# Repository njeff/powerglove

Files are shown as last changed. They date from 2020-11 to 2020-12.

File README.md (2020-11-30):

# powerglove

Jeffrey Ni and Leon Wu

WIP haptic feedback distance sensing glove.

### PCB

<p align="center">
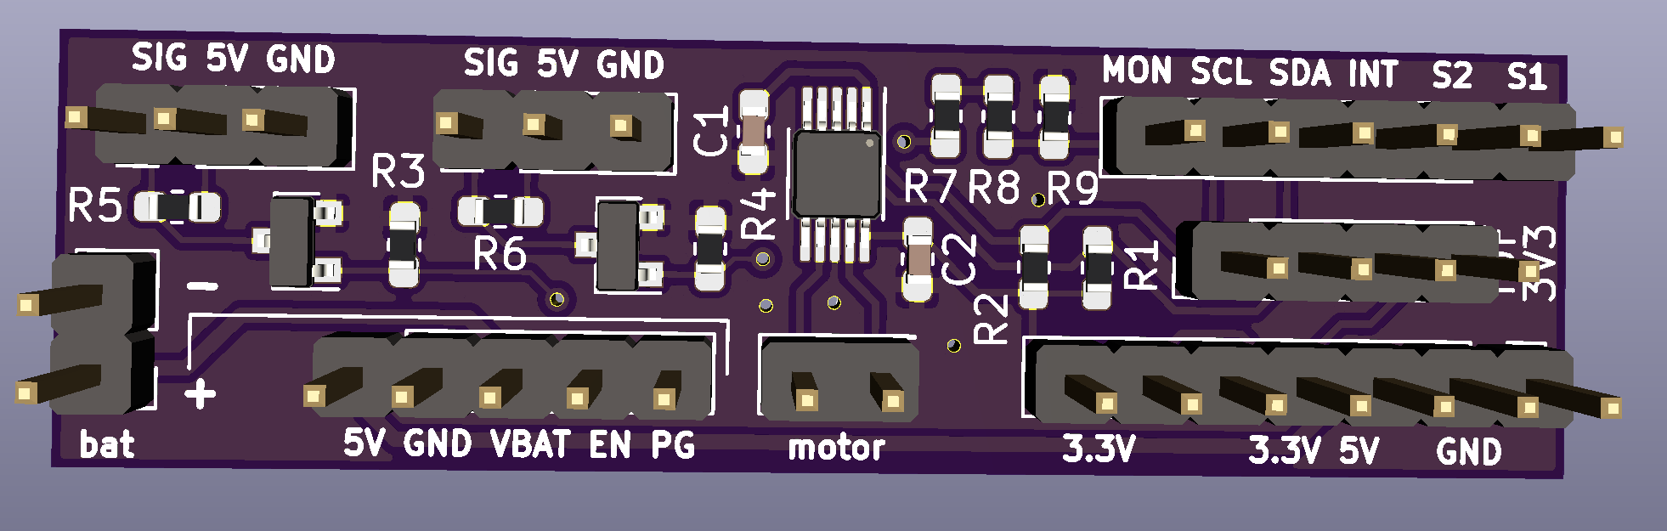
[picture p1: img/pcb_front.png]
    
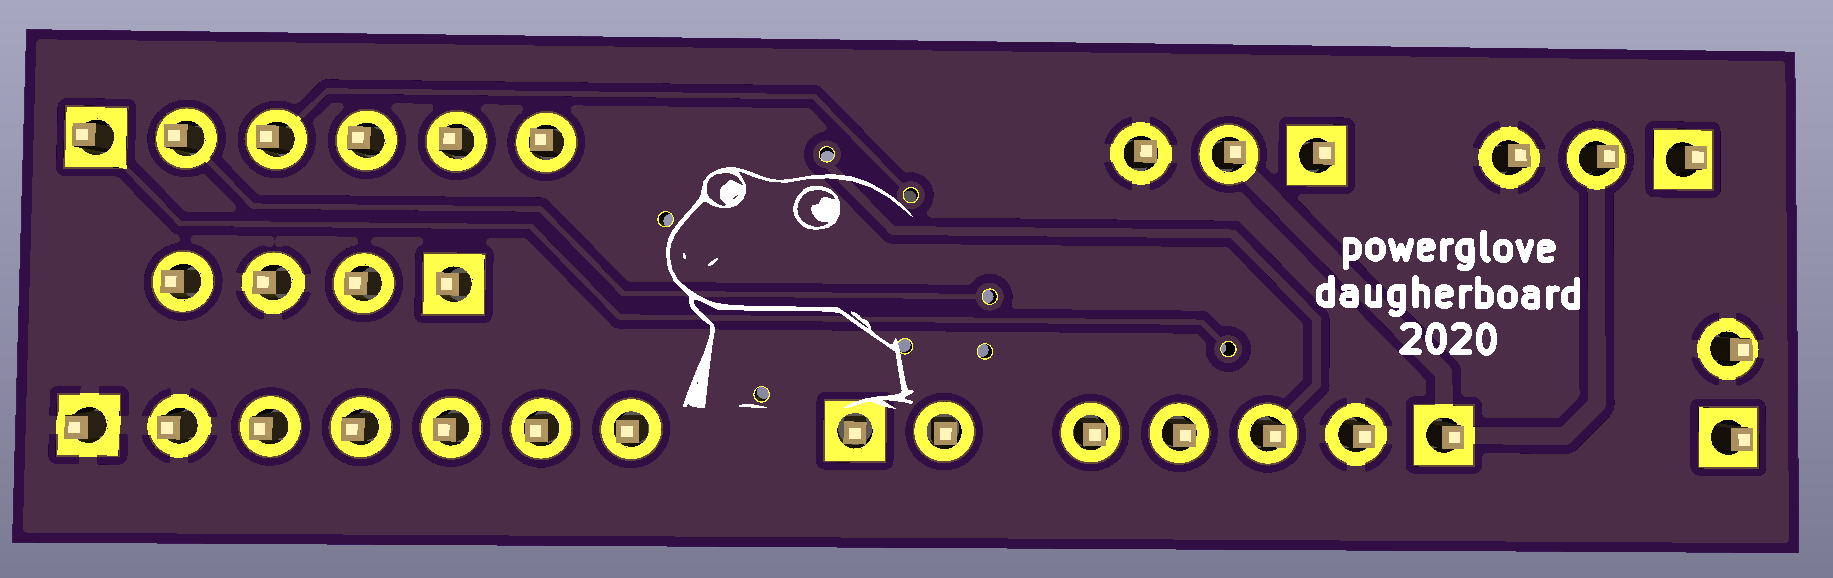
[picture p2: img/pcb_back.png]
    
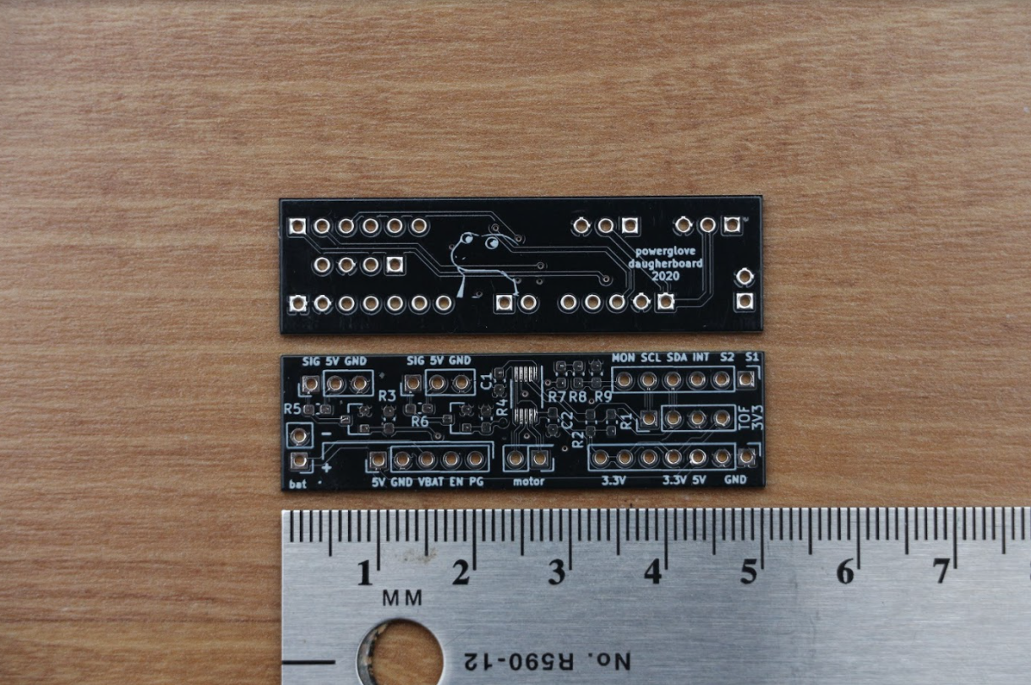
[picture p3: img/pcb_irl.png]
     
</p>

### Hardware Design

<p align="center">
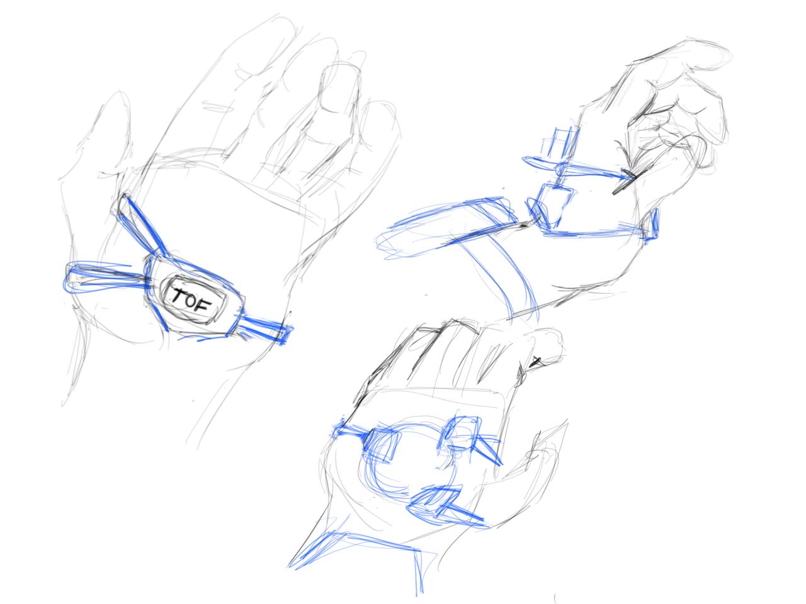
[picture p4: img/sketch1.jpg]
    
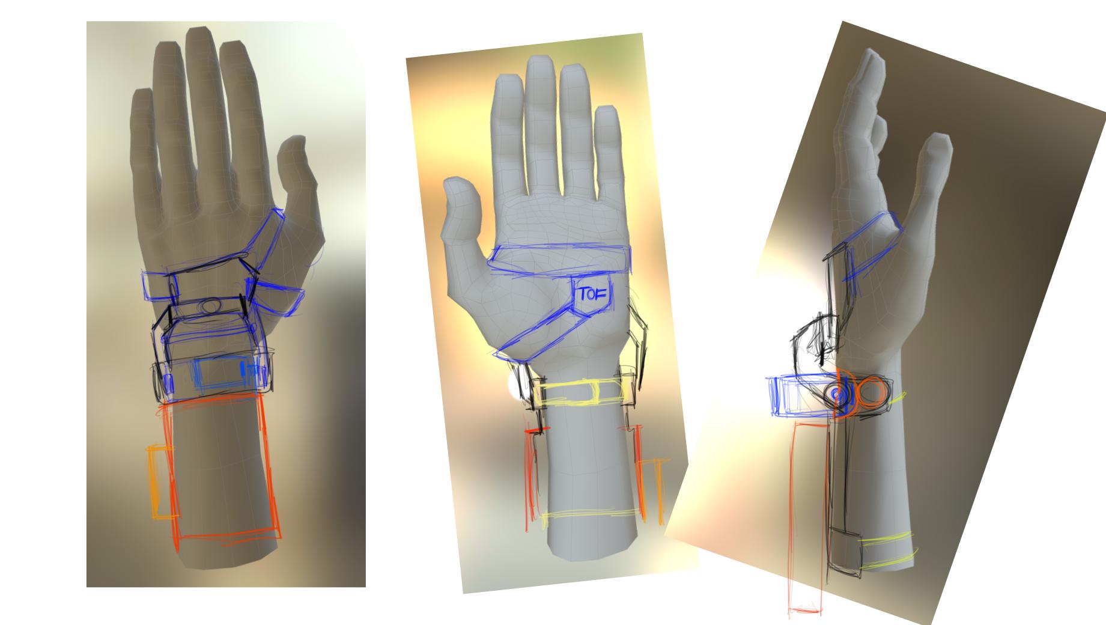
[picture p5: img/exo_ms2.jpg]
    
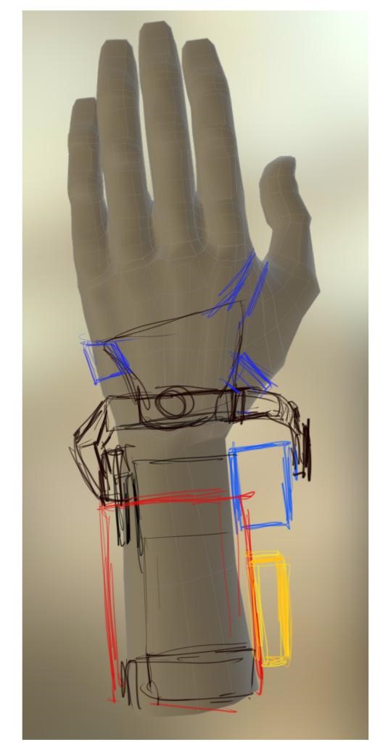
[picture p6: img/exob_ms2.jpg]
     
</p>

### Integration

<p align="center">
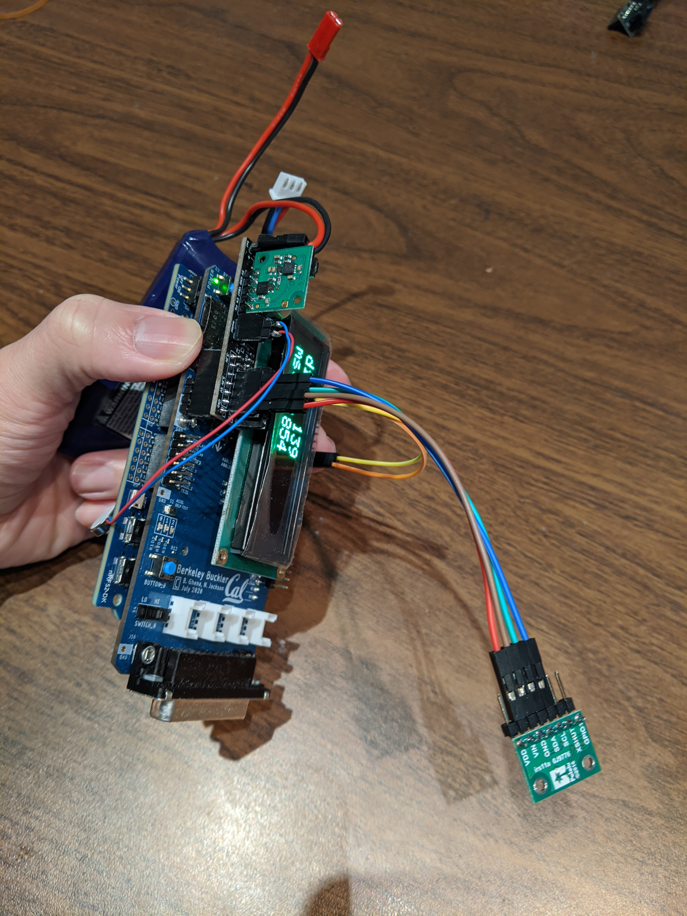
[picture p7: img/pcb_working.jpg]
    
</p>

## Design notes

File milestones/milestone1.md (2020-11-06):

# Milestone 1

## Git Repo
https://github.com/njeff/powerglove

## Architecture Drawing

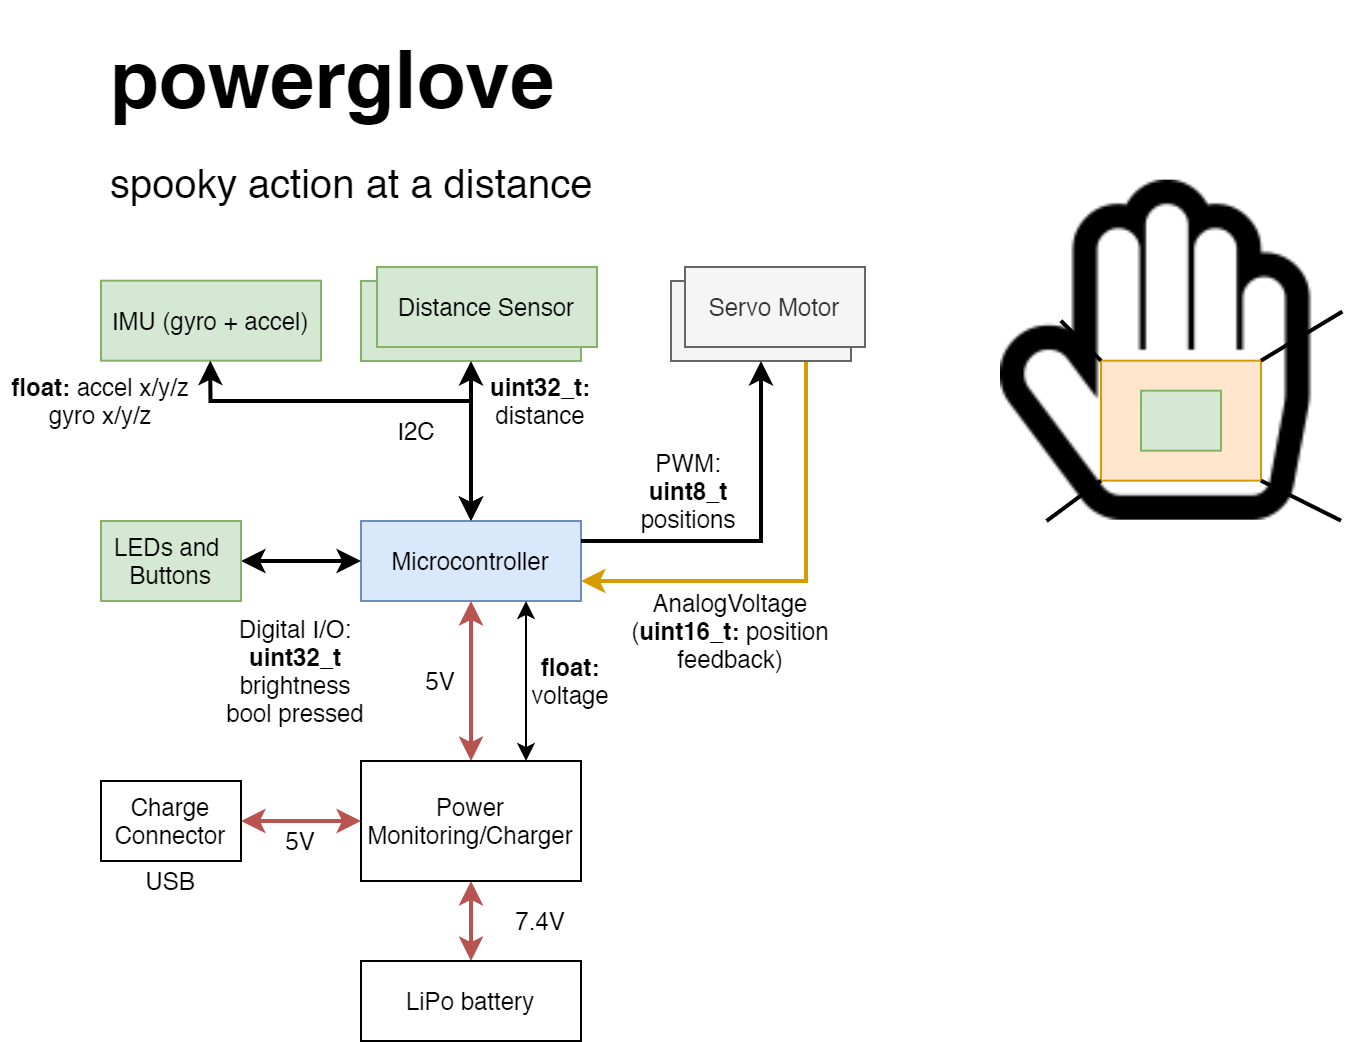
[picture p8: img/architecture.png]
Architecture Drawing


## Conceptual Sketch

Sketch

## Sensors

Ideally, the sensors are small, simple devices that can easily be integrated into the user's hand. 

* Distance/Proximity Sensor(s) - Time of Flight
    * VL53L0 - Time of Flight Distance Ranging Sensor: breakout boards are pretty flat, i2c interface with 1mm resolution, ~30mm-1m linear sensing
* Acceleration/Velocity Sensor - Simple 3/6DoF Velocity Sensing
    * NRF built in? 
    * 6DOF IMU - i.e. LSM6DS3, MPU6050
    * Provides essential secondary input signal for tracking hand motion

## Actuators

For actually generating the force, we plan to have some servos linked to a plate in the palm

* 2 or 3 micro servomotors mounted on the back of the hand that have position feedback outputs (e.g. [this](https://www.pololu.com/product/3436).)
* Some inspiration for the idea came from [this video on haptics](https://www.youtube.com/watch?v=UFgp7A1IK7o).

## Resources

We will use existing libraries for the distance sensor, found [here](https://www.st.com/en/embedded-software/stsw-img005.html). They may need slight porting for use with the NRF which we can do.

The IMU, if we use the one on the boards we have, already has libraries for it from lab.

Mechanical assembly: between the 2 of us exist:
* CNC mill
* 3D printer
* Various mechanical and electrical components

## Additional Circuits

* Portable Power: LiPo (7.4V) and charging/monitoring circuit
    * Detect low charge and enter low power mode or turn off

## Possible Risks

* The major risk is getting hardware (like the actual hand mount and actuators) up in a reasonable time. This takes CAD work, manufacturing, and multiple interations that can take time from software development and refinement of the "embedded system" as a whole.
* Haptic feedback not enough for appropriate user response, need testing of the human interaction early.

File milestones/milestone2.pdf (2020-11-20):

## powerglove: milestone 2

Jeffrey Ni and Leon Wu

## Progress

- PCB design done and sent out for fabrication:

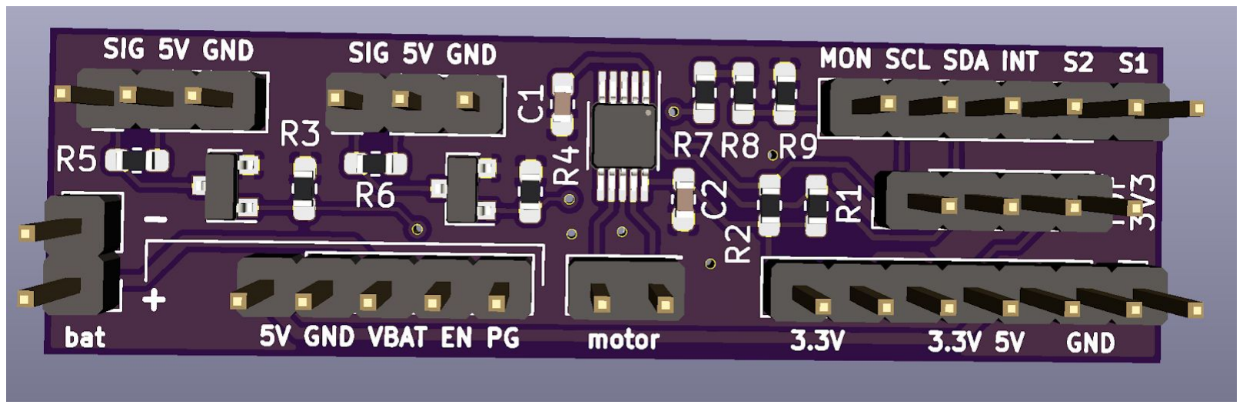
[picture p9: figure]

- Toolchain setup for the Buckler and our Custom FW
- Already have the firmware driver for the haptics ready; just need to test on actual hardware
- See at: https://github.com/njeff/powerglove
- Initial state machine plan (this may change to include a calibration phase for the hand with the servo feedback):

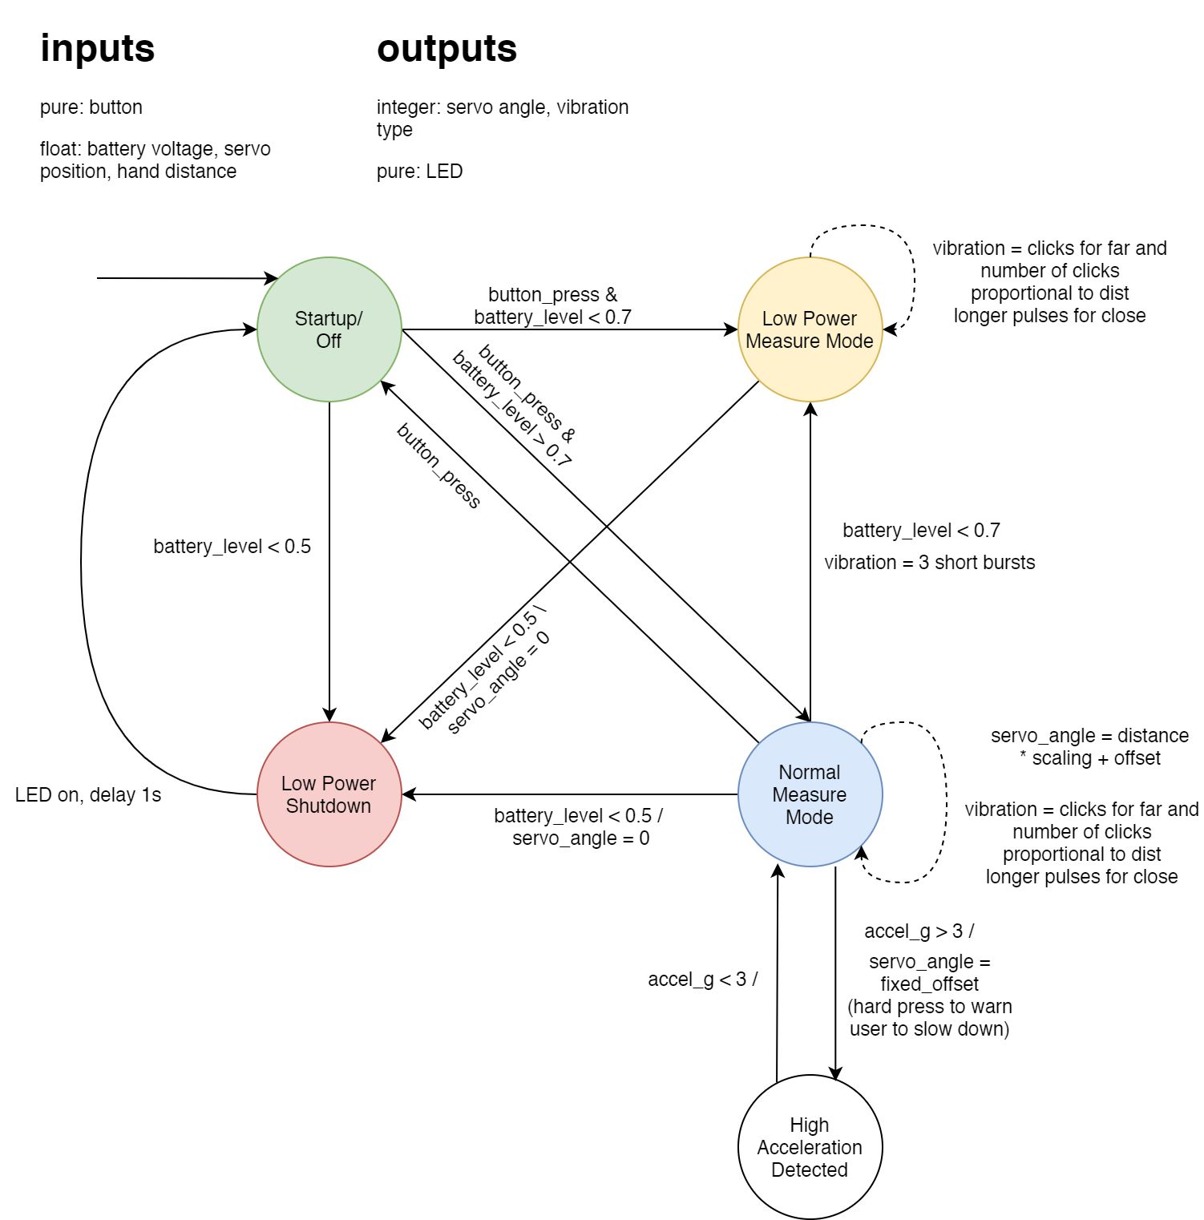
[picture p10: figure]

- Have some initial mock-ups of the mechanical design in cardboard
- We need to more carefully consider the servo mounting position as well as whether we have direct or indirect actuation.

## Changes to Scope

- Single servo palm actuator and vibration motors w/ special drivers for more than just on/off vibration
- Reduces mechanical complexity and reduces power draw

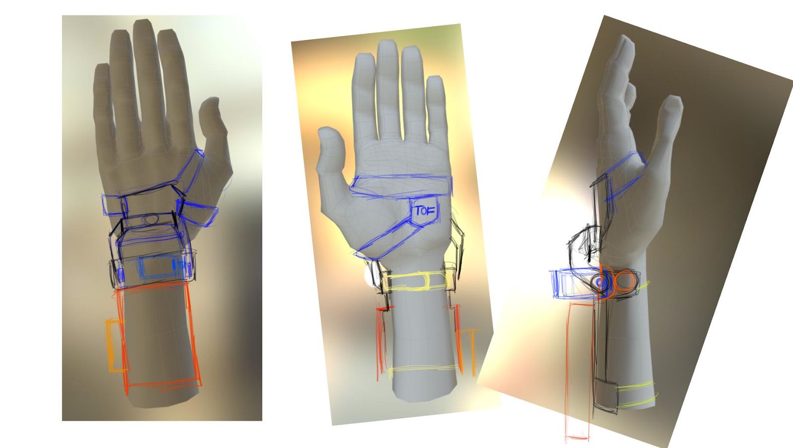
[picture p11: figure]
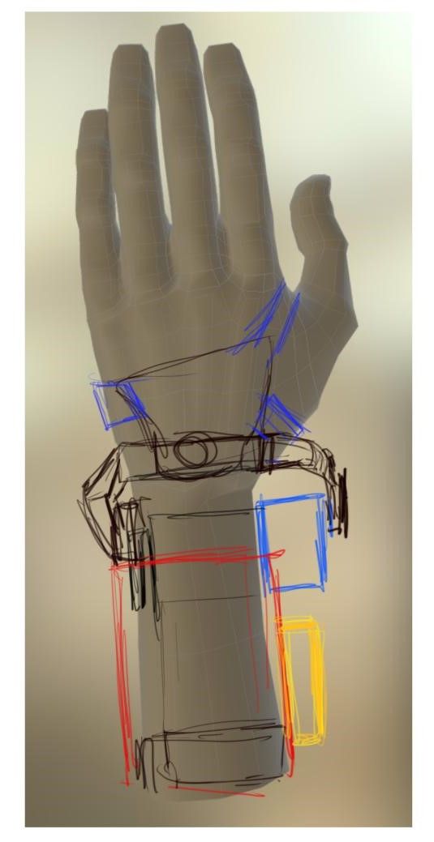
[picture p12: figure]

- How the device will actually operate is still mostly in the air, simply due do the fact that we need to experience the haptics in order to better understand how they should be used

## Resources to Still Get

- Hardware is on the way: ordered parts, PCB
- Already have the vibration motors, jumpers, and battery here
- Should not need anything extra (hopefully)
- From a code standpoint, we still need to work on porting over drivers for one of the sensors, but the main foundation is there.
- Not so much a resource, but we need to think more about how to mount the servo and the actuation arm.
- Likely need different servo horn

## Schedule of Remaining Time

- 10/28: Project proposal complete
- 11/4: Lock down the scope of what kind of haptic actuator/force we want to use
- 11/6: Milestone 1: Design state machine for this system
- 11/12: PCB sent out for manufacturing, initial prototyping of the physical layout done

- 11/16: Milestone 2: Code for initial haptic movement running; can see movement on breadboard system (parts likely come around now - update: not yet...)
- Leon: have some preliminary CAD or real-life mock-up design of the actuator
- Jeffrey: port ToF sensor driver and have servos working
- 11/18: Leon: mechanical mockups on actual arm
- 11/20: Continued refinement, Jeffrey: hopefully receive custom PCB and assemble
- 11/25: Both of us: First full integration on hand, simultaneously work on improving fit and haptic function
- 11/30: Both: Refined hardware working
- 12/2: Continued testing, begin writing report and create video
- 12/9: Both: Finalize everything
- 12/15: Project Expo, report due two days later

## Risks

The main risk is still the same one as before: getting hardware working is nontrivial and integration is not that simple, especially when designing for a portable application on the hand. We do now have a fall back though with the haptic motors in case the physical servo drive turns out to be too difficult to get working in time (but at the very least we would have it working on the bench and not on the hand).

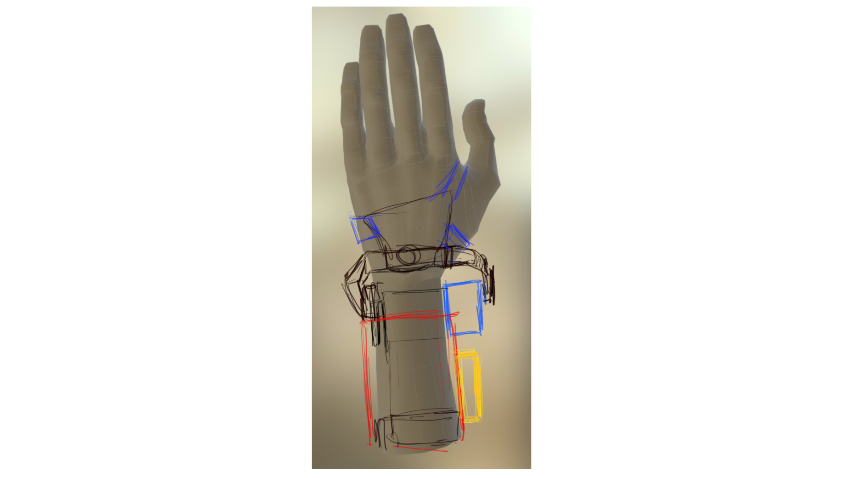
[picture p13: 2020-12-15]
img/exob_ms2.tif

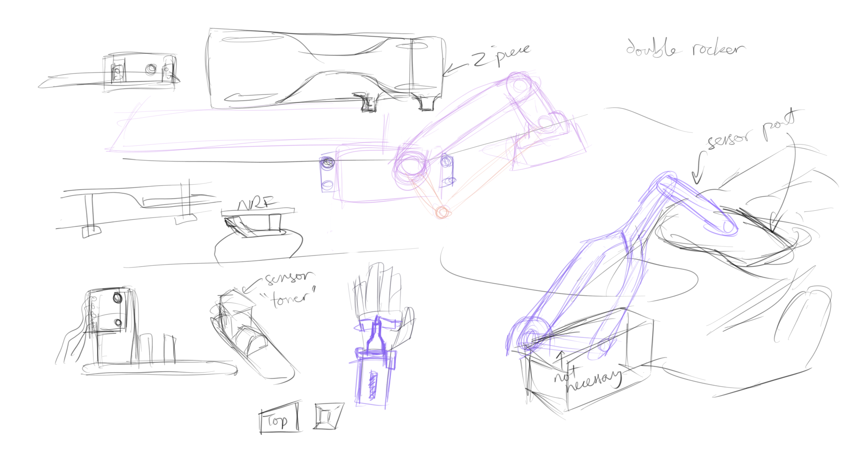
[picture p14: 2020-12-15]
img/exoc_bar1.tif

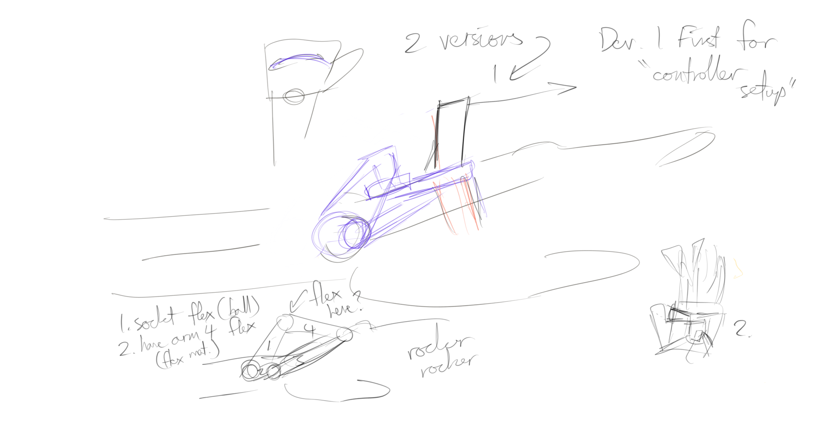
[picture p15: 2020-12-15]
img/exoc_bar.tif

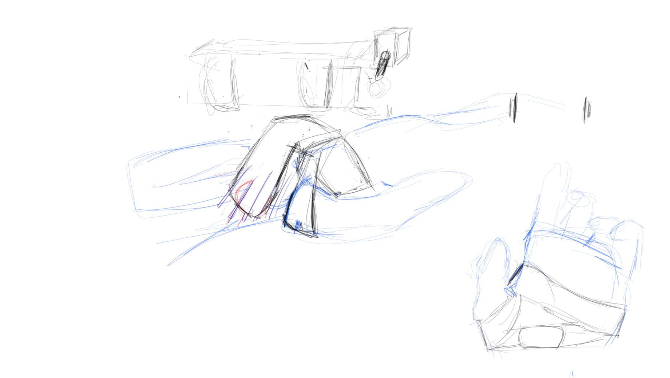
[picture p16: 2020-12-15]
img/temp.tif

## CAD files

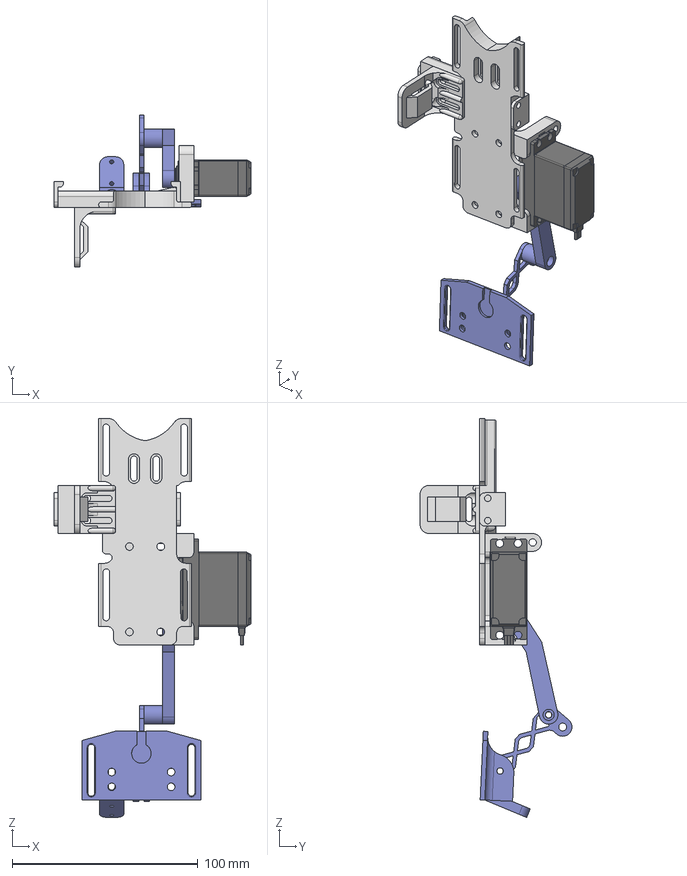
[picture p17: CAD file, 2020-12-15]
mechanical/left_assembly.step
105.9 x 81.8 x 215.0 mm
servo
fullwrist
servohorn
standoff
flex_linkage
battery_slotter
flat_side_clip x 2

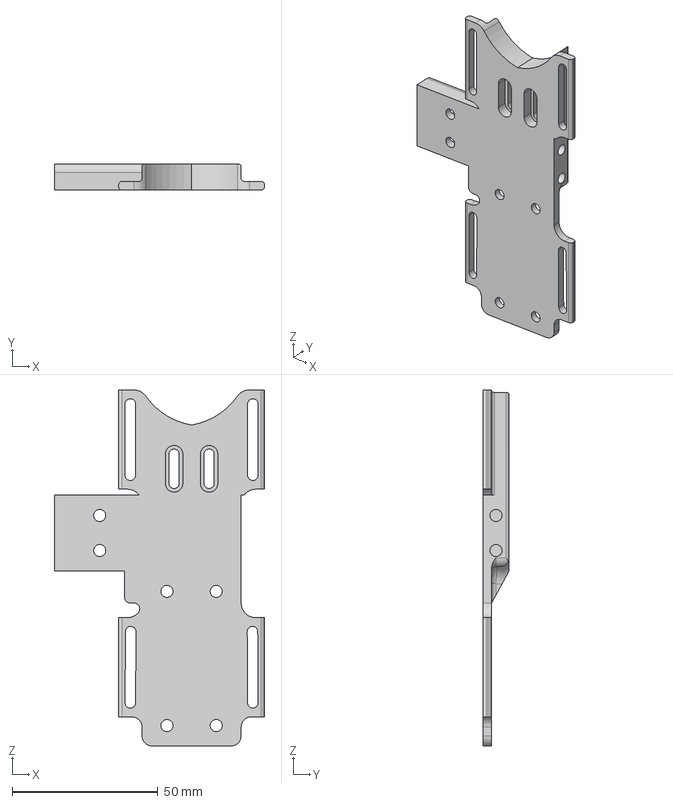
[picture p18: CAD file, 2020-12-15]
mechanical/fullwrist.step
72.0 x 9.00 x 122.0 mm

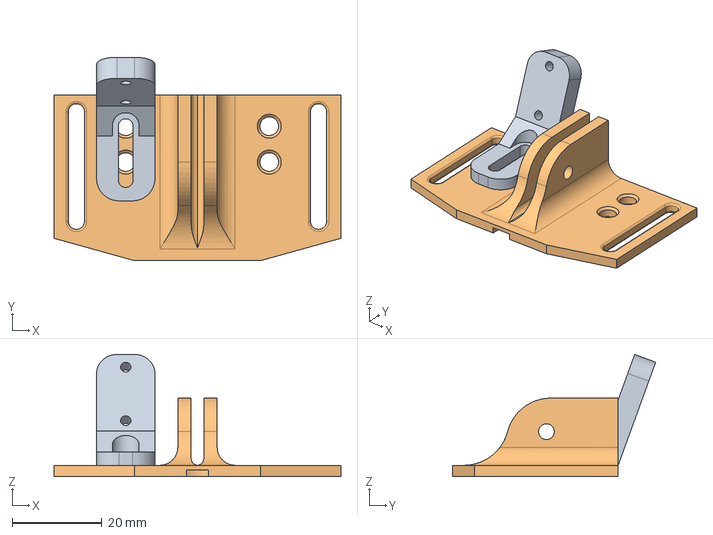
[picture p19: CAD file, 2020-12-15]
mechanical/back_hand.step
64.0 x 45.4 x 27.2 mm

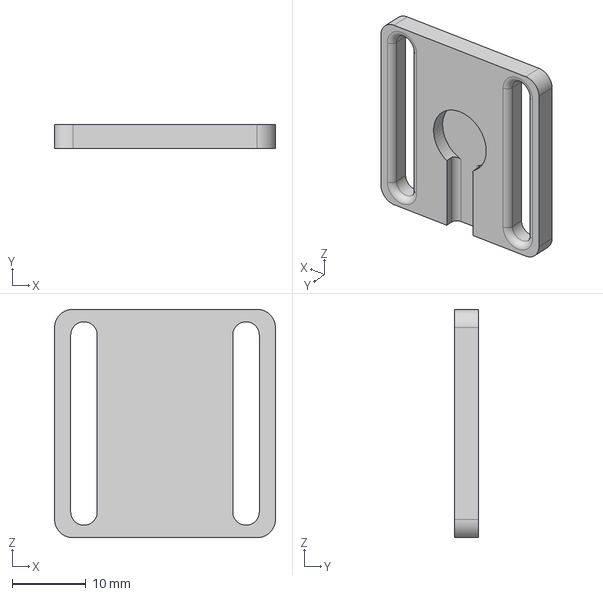
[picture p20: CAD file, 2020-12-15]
mechanical/palm_sensorless.step
30.0 x 3.20 x 31.0 mm

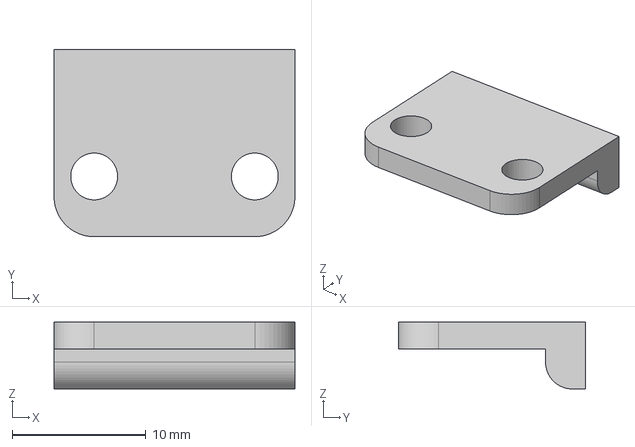
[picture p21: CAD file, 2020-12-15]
mechanical/flat_side_clip.step
18.0 x 14.0 x 5.00 mm

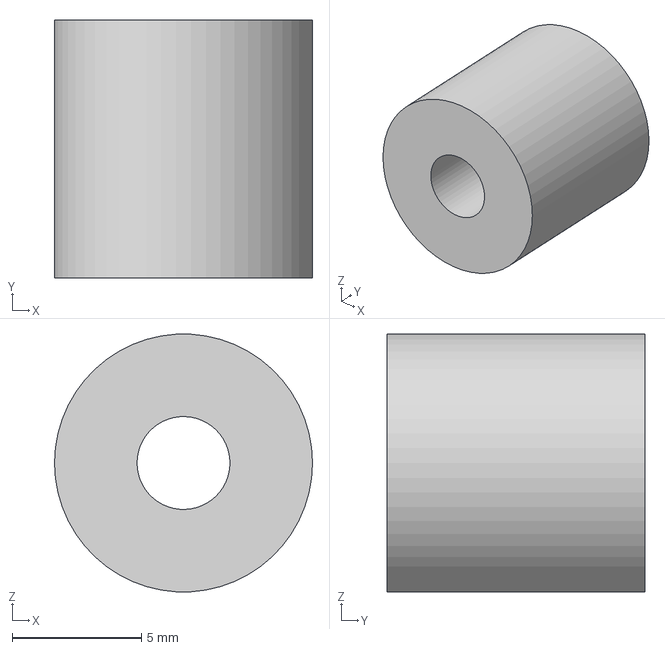
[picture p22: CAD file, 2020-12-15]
mechanical/standoff.step
10.0 x 10.0 x 9.98 mm

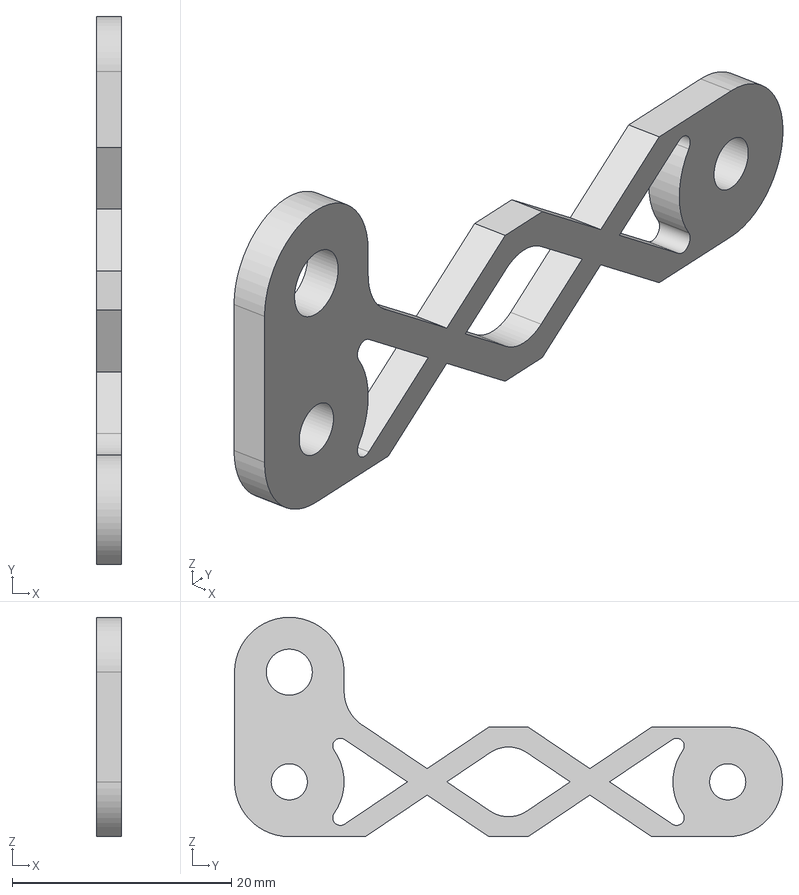
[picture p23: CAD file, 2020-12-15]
mechanical/flex_linkage.step
2.30 x 50.0 x 20.0 mm

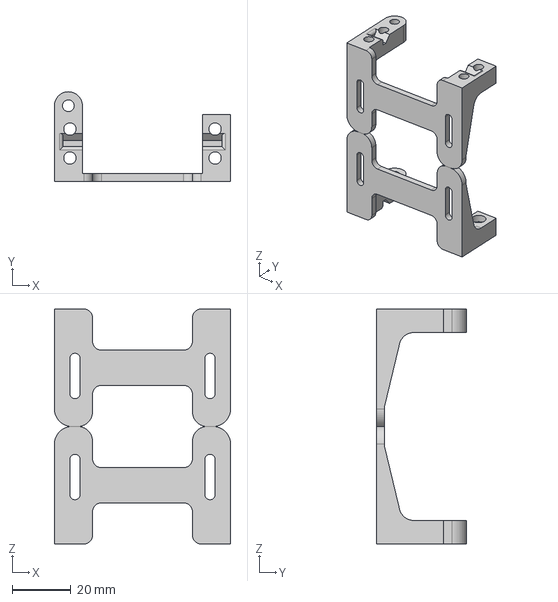
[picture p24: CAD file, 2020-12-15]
mechanical/servo_mount.step
60.0 x 30.5 x 80.0 mm

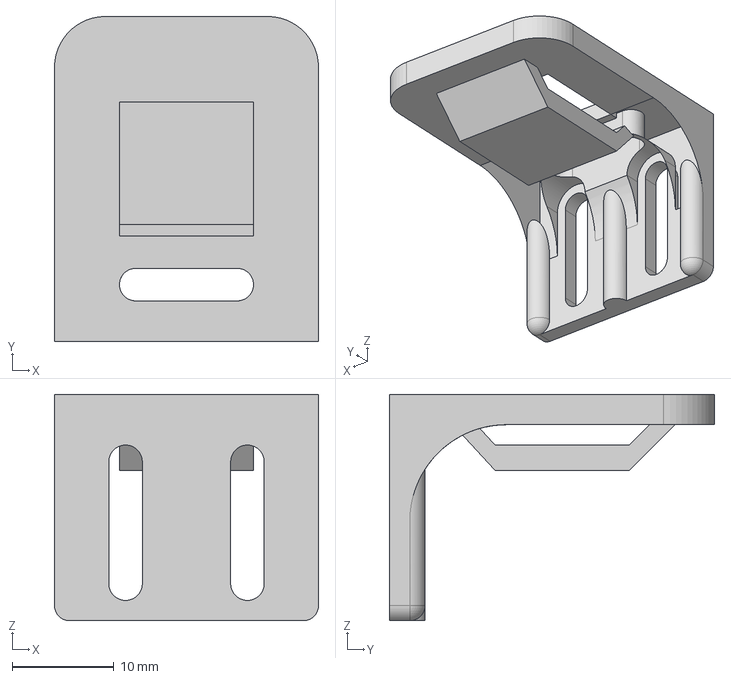
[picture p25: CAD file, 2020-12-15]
mechanical/battery_slotter.step
26.0 x 32.0 x 22.3 mm

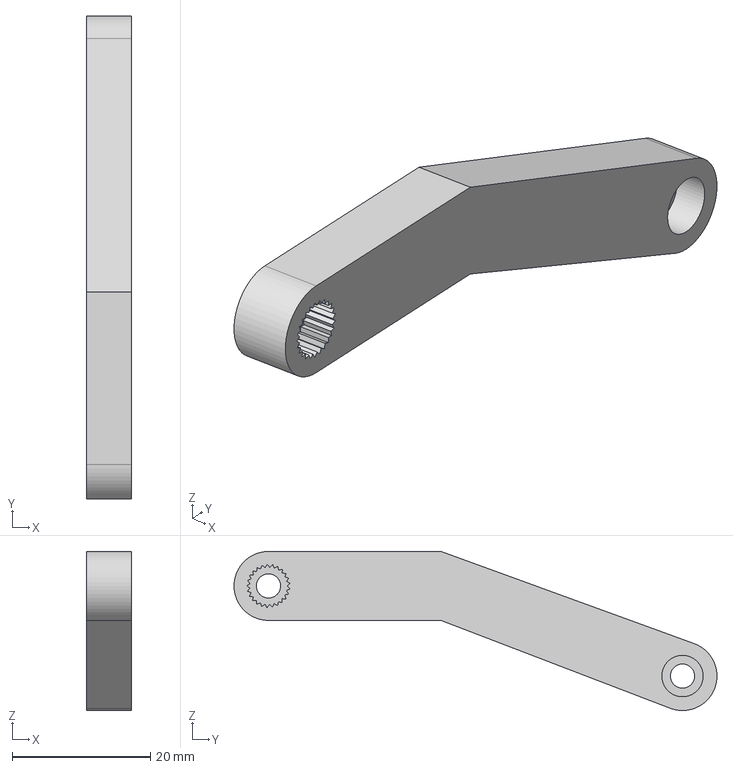
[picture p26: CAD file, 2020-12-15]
mechanical/servohorn.step
6.50 x 70.0 x 23.1 mm

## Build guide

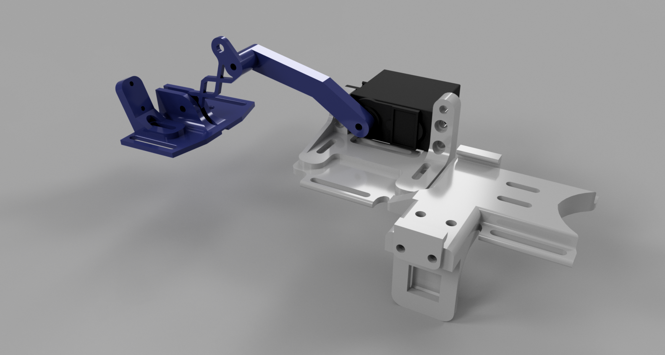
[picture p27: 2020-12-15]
mechanical/left_assembly_render.png

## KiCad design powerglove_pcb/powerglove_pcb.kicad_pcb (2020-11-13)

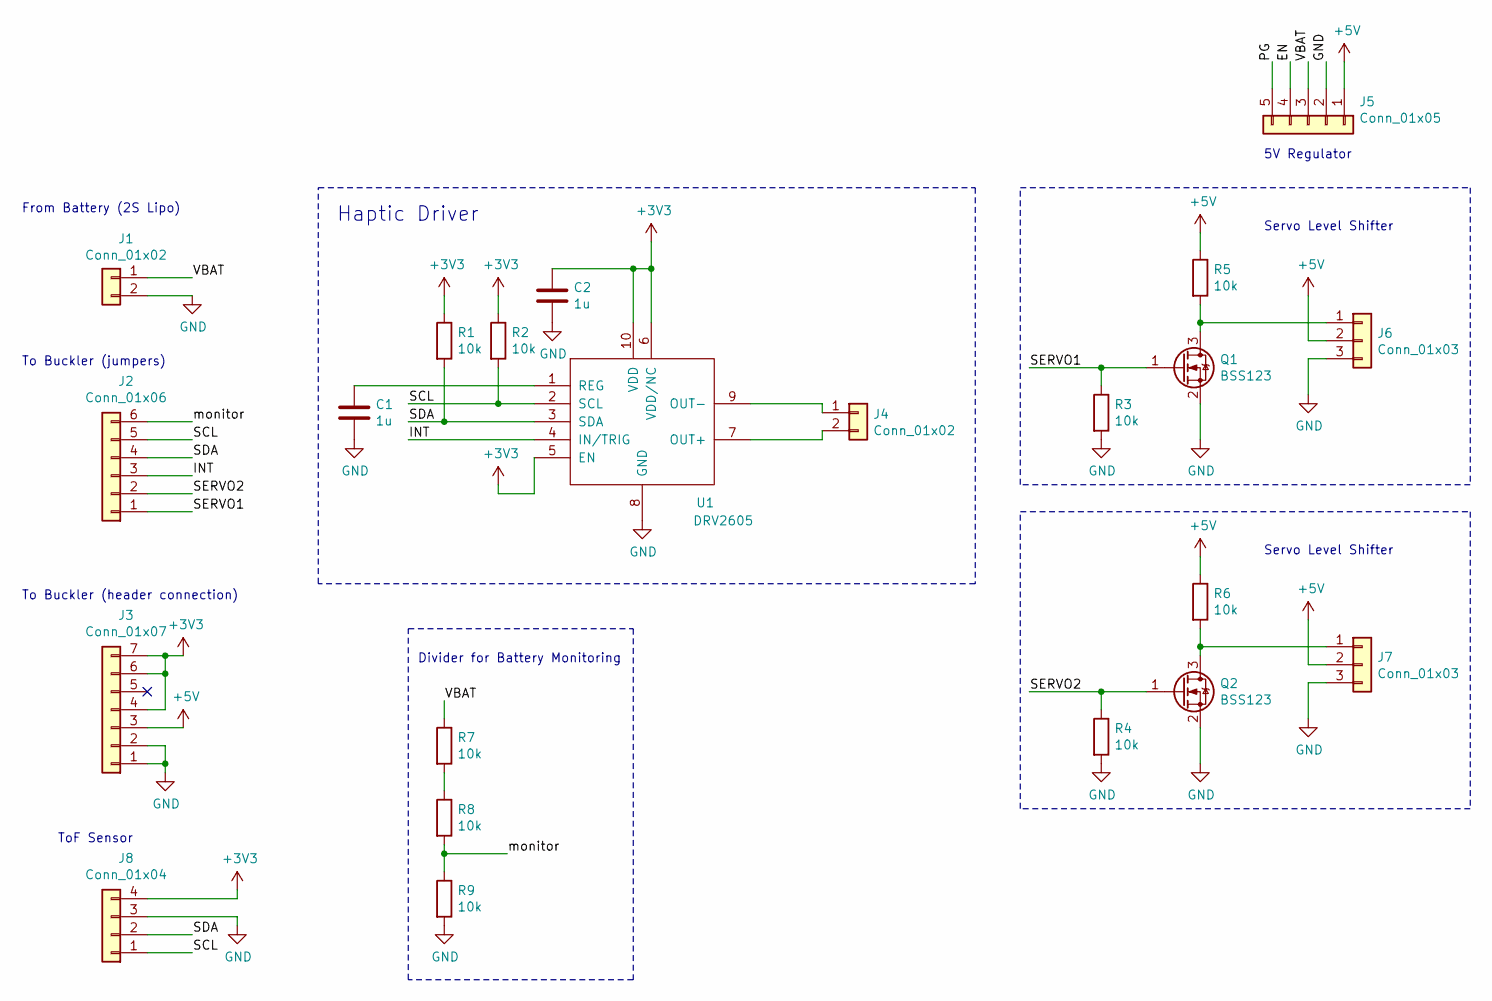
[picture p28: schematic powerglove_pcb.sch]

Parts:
C1, C2: 1u; C_0603_1608Metric_Pad1.05x0.95mm_HandSolder
J1: Conn_01x02; PinHeader_1x02_P2.54mm_Vertical
J2: Conn_01x06; PinHeader_1x06_P2.54mm_Vertical
J3: Conn_01x07; PinHeader_1x07_P2.54mm_Vertical
J4: Conn_01x02; PinHeader_2x01_P2.54mm_Vertical
J5: Conn_01x05; PinHeader_1x05_P2.54mm_Vertical
J6, J7: Conn_01x03; PinHeader_1x03_P2.54mm_Vertical
J8: Conn_01x04; PinHeader_1x04_P2.54mm_Vertical
Q1, Q2: BSS123; SOT-23
R1, R2, R3, R4, R5, R6, R7, R8, R9: 10k; R_0603_1608Metric_Pad1.05x0.95mm_HandSolder
U1: DRV2605; VSSOP-10_3x3mm_P0.5mm

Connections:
+3V3: C2.1, J3.4, J3.6, J3.7, J8.4, R1.1, R2.1, U1.5 (EN), U1.6 (VDD/NC), U1.10 (VDD)
+5V: J3.3, J5.1, J6.2, J7.2, R5.1, R6.1
/EN: J5.4
/INT: J2.3, U1.4 (IN/TRIG)
/PG: J5.5
/SCL: J2.5, J8.1, R2.2, U1.2 (SCL)
/SDA: J2.4, J8.2, R1.2, U1.3 (SDA)
/SERVO1: J2.1, Q1.1 (G), R3.1
/SERVO2: J2.2, Q2.1 (G), R4.1
/VBAT: J1.1, J5.3, R7.1
/monitor: J2.6, R8.2, R9.1
GND: C1.2, C2.2, J1.2, J3.1, J3.2, J5.2, J6.3, J7.3, J8.3, Q1.2 (S), Q2.2 (S), R3.2, R4.2, R9.2, U1.8 (GND)
unnamed: C1.1, U1.1 (REG)
unnamed: J4.1, U1.9 (OUT-)
unnamed: J4.2, U1.7 (OUT+)
unnamed: J6.1, Q1.3 (D), R5.2
unnamed: J7.1, Q2.3 (D), R6.2
unnamed: R7.2, R8.1

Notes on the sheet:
5V Regulator
Haptic Driver
Servo Level Shifter
To Buckler (header connection)
To Buckler (jumpers)
From Battery (2S Lipo)
ToF Sensor
Divider for Battery Monitoring

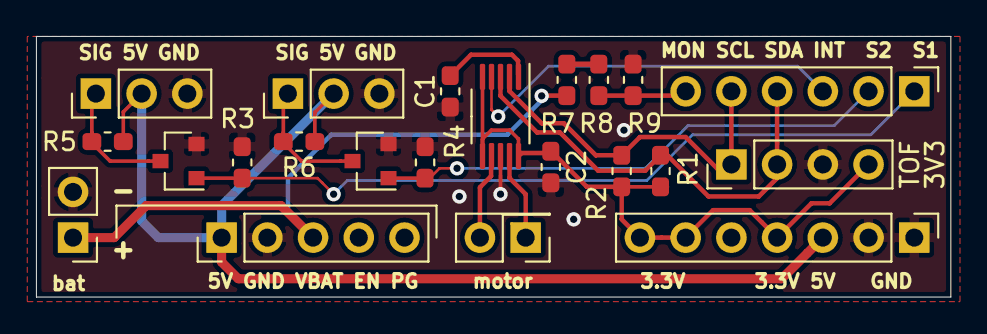
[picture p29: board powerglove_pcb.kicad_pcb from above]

Board: 2 copper layers, 50.8 x 14.5 mm, 22 parts (0 on the bottom side), 16 nets.

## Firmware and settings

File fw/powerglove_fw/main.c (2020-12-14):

// Powerglove Firmware

#include <stdbool.h>
#include <stdint.h>
#include <stdio.h>

#include "app_error.h"
#include "nrf.h"
#include "nrf_delay.h"
#include "nrfx_gpiote.h"
#include "nrf_gpio.h"
#include "nrf_log.h"
#include "nrf_log_ctrl.h"
#include "nrf_log_default_backends.h"
#include "nrf_pwr_mgmt.h"
#include "nrf_twi_mngr.h"
#include "nrf_serial.h"
#include "nrf_drv_spi.h"
#include "display.h"
#include "app_timer.h"

#include "buckler.h"
#include "lsm9ds1.h"
#include "drv2605l.h"
#include "vl53l0x.h"
#include "millis.h"
#include "util.h"
#include "states.h"

// LED array
static uint8_t LEDS[3] = {BUCKLER_LED0, BUCKLER_LED1, BUCKLER_LED2};

NRF_TWI_MNGR_DEF(twi_mngr_instance, 5, 0);

glove_state_t (*pStateFunc)();
glove_state_t state;

int main(void) {
  ret_code_t error_code = NRF_SUCCESS;

  // initialize timer, necessary for the ToF sensor
  millisInit();

  // initialize servo
  servoInit();
  setServoAngle(0, -1);

  // initialize ADC reading for battery and servo FB
  adcInit();

  buttonInit();

  // initialize i2c master (two wire interface)
  nrf_drv_twi_config_t i2c_config = NRF_DRV_TWI_DEFAULT_CONFIG;
  i2c_config.scl = BUCKLER_SENSORS_SCL;
  i2c_config.sda = BUCKLER_SENSORS_SDA;
  i2c_config.frequency = NRF_TWIM_FREQ_100K;
  error_code = nrf_twi_mngr_init(&twi_mngr_instance, &i2c_config);
  APP_ERROR_CHECK(error_code);

  // initialize display
  nrf_drv_spi_t spi_instance = NRF_DRV_SPI_INSTANCE(1);
  nrf_drv_spi_config_t spi_config = {
    .sck_pin = BUCKLER_LCD_SCLK,
    .mosi_pin = BUCKLER_LCD_MOSI,
    .miso_pin = BUCKLER_LCD_MISO,
    .ss_pin = BUCKLER_LCD_CS,
    .irq_priority = NRFX_SPI_DEFAULT_CONFIG_IRQ_PRIORITY,
    .orc = 0,
    .frequency = NRF_DRV_SPI_FREQ_4M,
    .mode = NRF_DRV_SPI_MODE_2,
    .bit_order = NRF_DRV_SPI_BIT_ORDER_MSB_FIRST
  };
  error_code = nrf_drv_spi_init(&spi_instance, &spi_config, NULL, NULL);
  APP_ERROR_CHECK(error_code);
  display_init(&spi_instance);
  //display_write("Hello, Human!", DISPLAY_LINE_0);

  // initialize GPIO driver
  if (!nrfx_gpiote_is_init()) {
    error_code = nrfx_gpiote_init();
  }
  APP_ERROR_CHECK(error_code);

  // configure leds
  // manually-controlled (simple) output, initially set
  nrfx_gpiote_out_config_t out_config = NRFX_GPIOTE_CONFIG_OUT_SIMPLE(true);
  for (int i=0; i<3; i++) {
    error_code = nrfx_gpiote_out_init(LEDS[i], &out_config);
    APP_ERROR_CHECK(error_code);
  }

  // init imu
  lsm9ds1_init(&twi_mngr_instance);
  printf("lsm9ds1 initialized\n");

  // init haptic
  initDRV2605(&twi_mngr_instance);
  printf("drv2605 initialized\n");

  // try ToF
  VL53L0X_init(true, &twi_mngr_instance);
  printf("tof initialized\n");
  VL53L0X_startContinuous(0); // measure as fast as possible

  // loop forever
  state = OFF;
  pStateFunc = state_map[state];
  state_data_t state_info;
  state_info.cal = 0;

  // debugging; start off calibrated
  /*
  state_info.cal = 2;
  state_info.lower_angle = 65;
  state_info.upper_angle = 135;
  */

  char buf[16];
  while (1) {
    // update all state variables
    state_info.dist = VL53L0X_readRangeContinuousMillimeters();
    state_info.voltage = readBattery();
    state_info.pressed = readButton(&state_info.hold_time);
    
    // do state functions
    state = pStateFunc(&state_info);
    pStateFunc = state_map[state];

    //nrf_delay_ms(50);
  }
}

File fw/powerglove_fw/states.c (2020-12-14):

#include "states.h"

#include <stdbool.h>
#include <math.h>

#include "nrf_gpio.h"
#include "nrf_delay.h"
#include "drv2605l.h"
#include "lsm9ds1.h"
#include "display.h"
#include "util.h"
#include "millis.h"

glove_state_t (*state_map[])(state_data_t *) = {
  off_state,
  calibration_state,
  active_state,
  sleep_state,
  lp_active_state
};

static char buf[16];
glove_state_t off_state(state_data_t *state_data) {
  sprintf(buf, "Off. Batt:%2.1f", state_data->voltage);
  display_write(buf, DISPLAY_LINE_0);
  sprintf(buf, "ms: %lu", millis());
  display_write(buf, DISPLAY_LINE_1);
  setServoAngle(0, -1);
  if (state_data->pressed) {
    if (state_data->cal == 0) {
      return CALIBRATION;
    } else {
      // if held down for > 1 sec, go to lower power active
      if (state_data->hold_time > 1000) {
        return LOW_POWER_ACTIVE;
      } else {
        if (state_data->voltage > 7) {
          return ACTIVE;
        } else {
          display_write("Low battery!", DISPLAY_LINE_1);
          nrf_delay_ms(1000);
        }
      }
    }
  }
  return OFF;
}

// calibrate the lower and upper limits
glove_state_t calibration_state(state_data_t *state_data) {
  setServoAngle(0, -1);
  display_write("Calibrating.", DISPLAY_LINE_0);

  uint8_t angle = fbVoltToAngle(readServoFB());
  if (state_data->cal == 0) {
    sprintf(buf, "Close Ang, %d", angle);
  } else if (state_data->cal == 1) {
    sprintf(buf, "Far Ang, %d", angle);
  }
  
  display_write(buf, DISPLAY_LINE_1);

  if (state_data->pressed) {
    if (state_data->cal == 0) {
      state_data->lower_angle = angle;
      state_data->cal = 1;
      return CALIBRATION;
    } else if (state_data->cal == 1) {
      state_data->upper_angle = angle;
      state_data->cal = 2;
      return ACTIVE;
    }
  }
  return CALIBRATION;
}

static bool moving = true;
static uint32_t last_move_time = 0;
glove_state_t active_state(state_data_t *state_data) {
  const int lowerDist = 50;
  const int upperDist = 500;
  const float gyro_thresh = 5;

  sprintf(buf, "Act. Batt:%2.1f", state_data->voltage);
  display_write(buf, DISPLAY_LINE_0);
  display_write("Running!", DISPLAY_LINE_1);
  lsm9ds1_measurement_t gyro_m = lsm9ds1_read_gyro();
  //printf("%2.1f, %2.1f, %2.1f\n", fabs(gyro_m.x_axis), fabs(gyro_m.y_axis), fabs(gyro_m.z_axis));

  if (fabs(gyro_m.x_axis) < gyro_thresh && 
      fabs(gyro_m.y_axis) < gyro_thresh && 
      fabs(gyro_m.z_axis) < gyro_thresh) {
    if (moving) {
      moving = false;
      last_move_time = millis();
    }
  } else {
    moving = true;
  }
  // after 10 sec of inactivity, sleep
  if (!moving && compareMillis(last_move_time, millis()) > 10000) {
    setServoAngle(0, -1);
    return SLEEP;
  }

  if (state_data->pressed) {
    return OFF;
  }

  if (state_data->voltage < 7) {
    display_write("Low battery!", DISPLAY_LINE_1);
    nrf_delay_ms(1000);
    return OFF;
  }

  // test ramp up and down
  DRV2605_setWaveform(0, 83);
  DRV2605_setWaveform(1, 71);
  DRV2605_setWaveform(2, 0);
  DRV2605_go();

  if (state_data->dist > upperDist) {
    setServoAngle(0, state_data->upper_angle);
  } else if (state_data->dist < lowerDist) {
    setServoAngle(0, state_data->lower_angle);
  } else {
    setServoAngle(0, (state_data->dist - lowerDist) * 
      (state_data->upper_angle - state_data->lower_angle) / (upperDist - lowerDist) + state_data->lower_angle);
  }

  return ACTIVE;
}

// if motion is not detected for awhile
glove_state_t sleep_state(state_data_t *state_data) {
  const float gyro_thresh = 5;
  display_write("Sleeping.", DISPLAY_LINE_0);
  display_write("Move to wake.", DISPLAY_LINE_1);
  setServoAngle(0, -1);

  lsm9ds1_measurement_t gyro_m = lsm9ds1_read_gyro();
  if (fabs(gyro_m.x_axis) > gyro_thresh || 
      fabs(gyro_m.y_axis) > gyro_thresh || 
      fabs(gyro_m.z_axis) > gyro_thresh) {
    // not sure if I like these somewhat global variables being set like this
    // between functions, but don't think they belong in the state data struct
    moving = true; 
    return ACTIVE;
  }

  if (state_data->pressed) {
    moving = true; 
    return OFF;
  }

  return SLEEP;
}

glove_state_t lp_active_state(state_data_t *state_data) {
  display_write("Low Power Mode", DISPLAY_LINE_0);
  
  if (state_data->pressed) {
    return OFF;
  }

  const int lowerDist = 50;
  const int upperDist = 500;

  // clamp
  int d = fmin(fmax(state_data->dist, lowerDist), upperDist);
  int levels = (d - lowerDist) * 8 / (upperDist - lowerDist);
  sprintf(buf, "lvl: %d", levels);
  display_write(buf, DISPLAY_LINE_1);

  if (levels < 2) {
    DRV2605_setWaveform(0, 1); // 100% strong click
  } else if (levels < 6) {
    DRV2605_setWaveform(0, 2); // 60% strong click
  } else {
    DRV2605_setWaveform(0, 3); // 30% strong click
  }
  DRV2605_setWaveform(1, 0);
  DRV2605_go();

  return LOW_POWER_ACTIVE;
}

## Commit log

2020-11-09 Inital schematic
    [powerglove_pcb.kicad_pcb, powerglove_pcb.sch]
2020-11-09 updated schematic with assigned footprints, ported into layout
    [powerglove_pcb.kicad_pcb, powerglove_pcb.sch]
2020-11-09 some prelimiary layout placement b4 nap
    [powerglove_pcb.kicad_pcb]
2020-11-13 Added ToF sensor header, arrange layout
    [powerglove_pcb.kicad_pcb, powerglove_pcb.sch]
2020-11-13 PCB layout complete
    [powerglove_pcb.kicad_pcb, powerglove_pcb.sch]
2020-11-13 update PCB layout for simple battery monitoring, clean up silk
    [powerglove_pcb.kicad_pcb, powerglove_pcb.sch]
2020-11-13 PCB pictures, froge, and supplied driver for ToF sensor (not yet ported)
    [powerglove_pcb.kicad_pcb]
2020-11-13 update raytraced pcb images and adjusted PCB back zone
    [powerglove_pcb.kicad_pcb]
2020-11-13 Generated gerbers
    [powerglove_pcb-B_Cu.gbr, powerglove_pcb-B_Mask.gbr, powerglove_pcb-B_SilkS.gbr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]
2020-11-15 Setup buckler toolchain
2020-11-15 Added haptic driver
2020-11-20 VL53L0X Pololu Driver initial port, untested
2020-11-23 Servo driver added, previous drivers tested
2020-11-26 Battery voltage reading
2020-11-30 Servo FB pin reading
2020-11-30 Debounced button
2020-12-01 Added simple calibration state
2020-12-09 Added low power state, changed button reading to handle hold duration
2020-12-14 Battery voltage cutoff
2020-12-15 12/14 add related mechanical files
    [back_hand.step, battery_slotter.step, flat_side_clip.step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]
